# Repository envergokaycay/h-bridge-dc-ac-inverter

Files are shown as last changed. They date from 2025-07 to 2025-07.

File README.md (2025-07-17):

# Wireless Power Transfer System for Electric Vehicles

> 👇 Below you can see the inverter board and a real-time working demo:

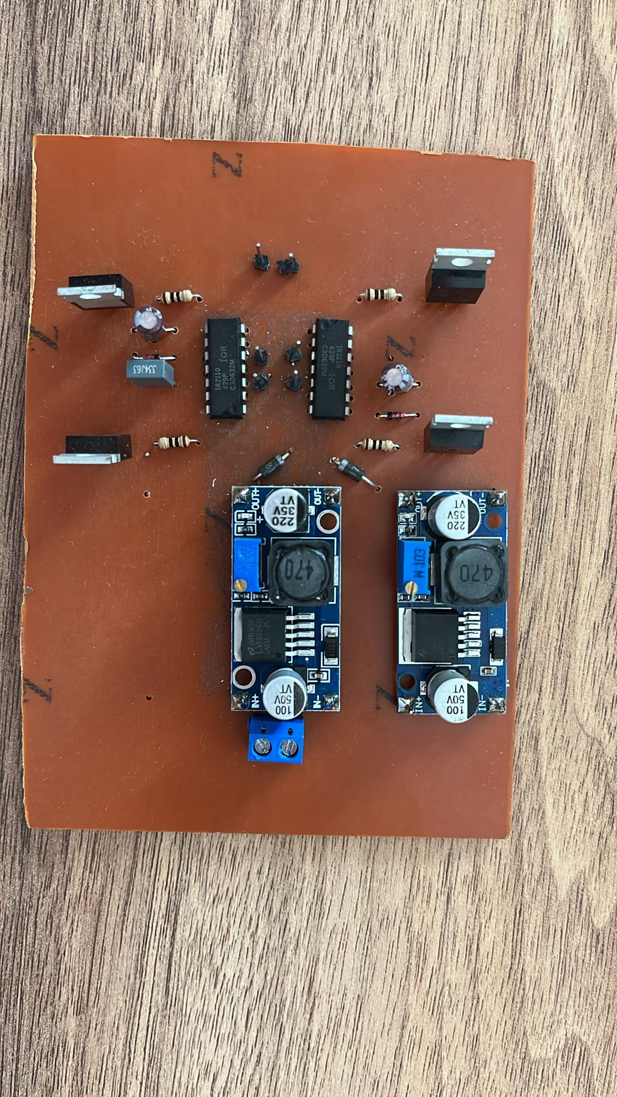
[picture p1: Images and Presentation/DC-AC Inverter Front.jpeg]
Inverter Front View


Operating Demo

## 📌 Project Summary
This project presents a **wireless power transfer (WPT)** system prototype aimed at demonstrating the basic principles of resonant inductive coupling for electric vehicle (EV) charging applications. The prototype is based on an **Arduino-controlled** system that generates a high-frequency AC output using a **H-bridge inverter**, optimized for energy transfer over short distances via an air-core coil pair.

This project was developed as a senior design (bitirme) project in the Electrical and Electronics Engineering Department.

---

## ⚙️ Technical Features

- **Input Voltage:** 24V DC
- **Output Voltage:** ~18V AC (square wave, measured ≈3V AC RMS on multimeter) 
- **Control:** Arduino Uno R3-based PWM generation
- **Topology:** H-Bridge Inverter using IRFZ44N MOSFETs and IR2110 Gate Drivers
- **Regulation:** LM2596 Buck Converter for voltage stepping
- **Rectification:** Fast recovery Schottky diodes at receiver side
- **PCB Design Software:** KiCad 9.0

---

## 🔧 Hardware and Software Used

- **Microcontroller:** Arduino Uno R3  
- **H-Bridge Topology:** Implemented using IRFZ44N MOSFETs  
- **Gate Driver:** IR2110  
- **DC-DC Regulator:** LM2596 (Used to step down the 24V input to 12V to power the IR2110 gate driver ICs. Additionally, another LM2596 module was configured to provide a 5V regulated output to safely interface the Arduino Uno R3’s PWM control signals with the IR2110 inputs.)  
- **Protection Diodes:** 1N5817 Schottky Diodes  
- **PCB Design:** KiCad 9.0 (schematic and PCB design)

---

## ⚙️ PCB Production

The PCB for the inverter stage was fully fabricated by hand, using personal resources and without relying on any professional PCB manufacturing service. The entire process — including etching, manual drilling, and component soldering — was carried out with basic tools, showcasing a hands-on, resourceful approach to hardware prototyping under limited conditions.

---

## 🧪 Testing and Results

- Square wave signal confirmed on the output using an oscilloscope  
- Successful power transfer to receiver coil  
- 3D visualization used for mechanical validation

---

## 📂 Suggested Folder Structure

- `DC-AC Inverter with H-Bridge/`  
  ├── `Code/`  
  ├── `Images and Presentation/`  
    ├── [Operating.mp4](https://www.youtube.com/shorts/zgLSwQ5zg5Q)  
    └── [Wireless Electric Vehicle Charging System KTU EEE.mp4](https://www.youtube.com/shorts/1_IPSUS-X5c)  
  ├── `PCB/`  
    ├── `3D/`  
    ├── `BOM/`  
    ├── `Drill/`  
    └── `Gerber/`  
  ├── `Schematics/`  
  ├── `Simulation Graphs/`  
  └── `README.md`

---

## 📝 Notes

- This circuit is part of a larger system intended to provide an efficient power transfer layer for wireless charging of electric vehicles.  
- All components were selected based on reliable datasheet references and added to KiCad libraries accordingly.

---

## 📚 Future Improvements

- Implement closed-loop current control via feedback
- Design custom receiver coil enclosure
- Replace Arduino with STM32 for better signal precision
- Improve EMI shielding and cooling

---

## 📬 Contact

If you have any questions or want to collaborate, feel free to reach out via GitHub or [LinkedIn](https://www.linkedin.com/in/envergokaycay/).

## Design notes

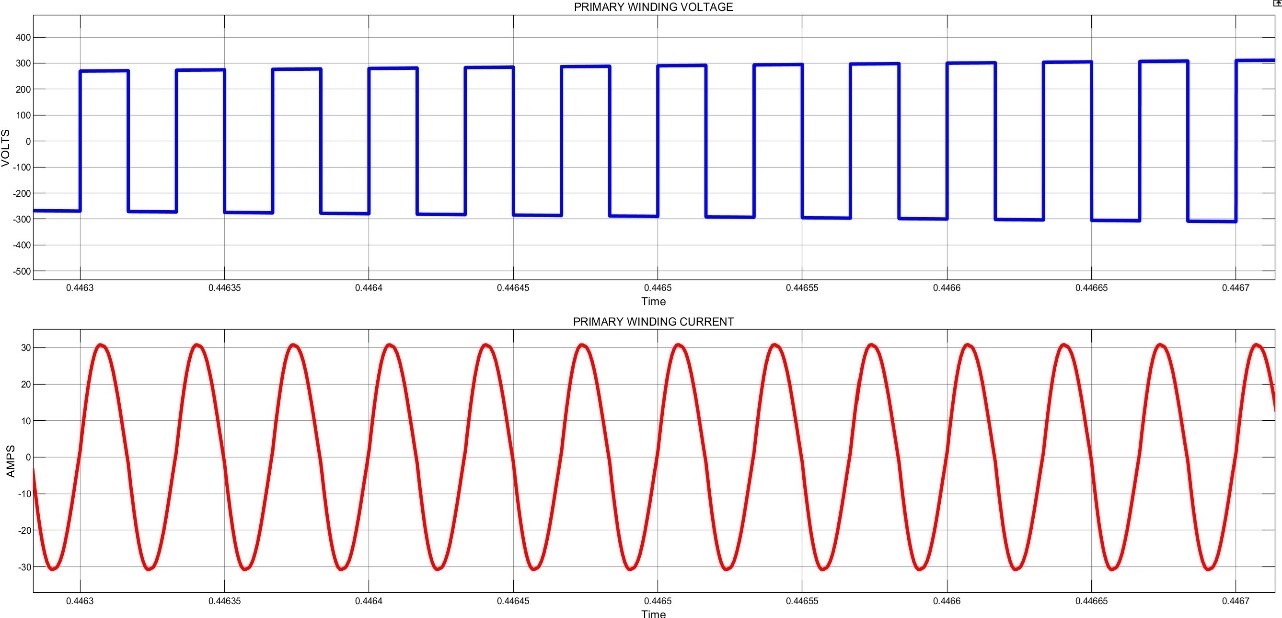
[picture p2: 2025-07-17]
Simulation Graphs/Primary Winding Graphs.jpg

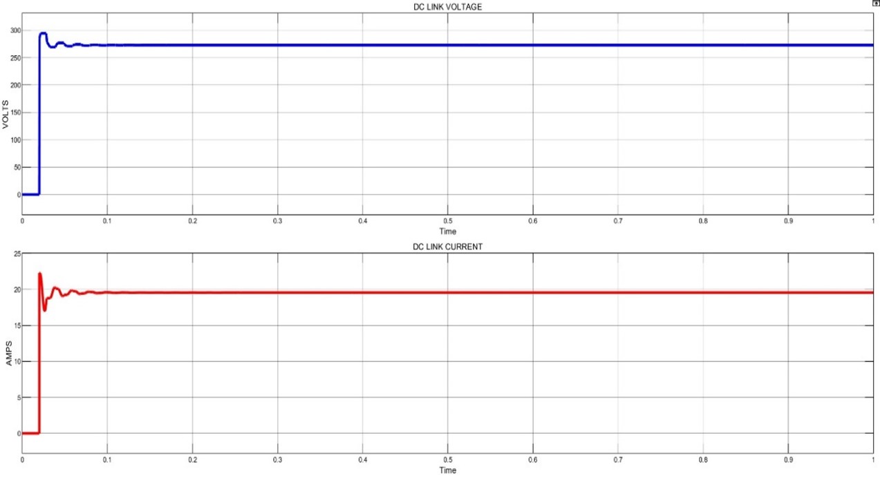
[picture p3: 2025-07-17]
Simulation Graphs/DC-Link Graphs.jpg

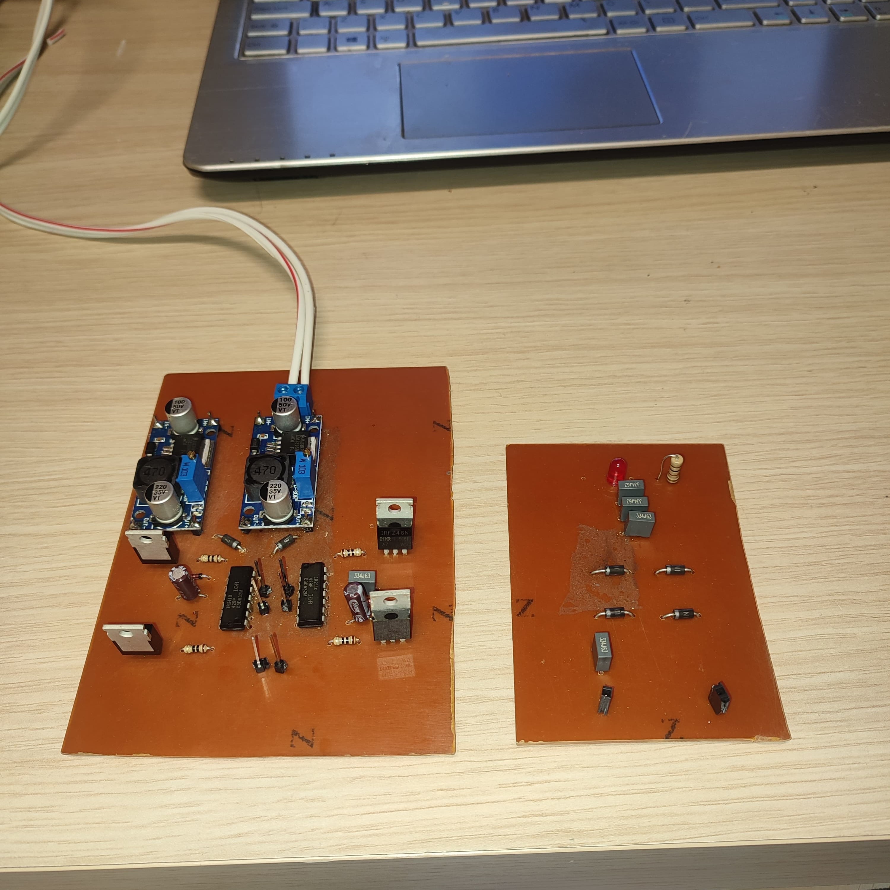
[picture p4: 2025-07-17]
Images and Presentation/Transmitter and Receiver.jpeg

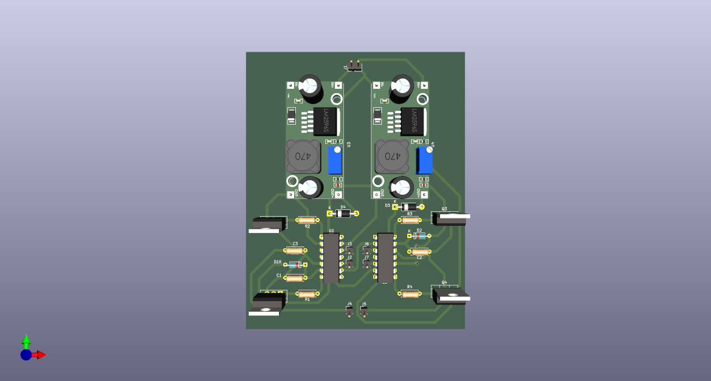
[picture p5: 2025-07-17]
PCB/3D/DC-AC Inverter.png

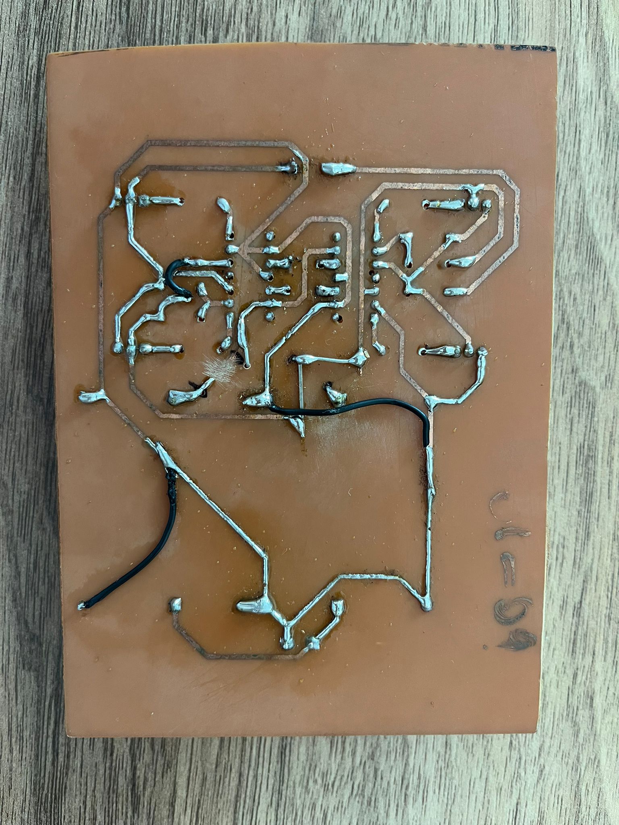
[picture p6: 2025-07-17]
Images and Presentation/DC-AC Inverter Back.jpeg

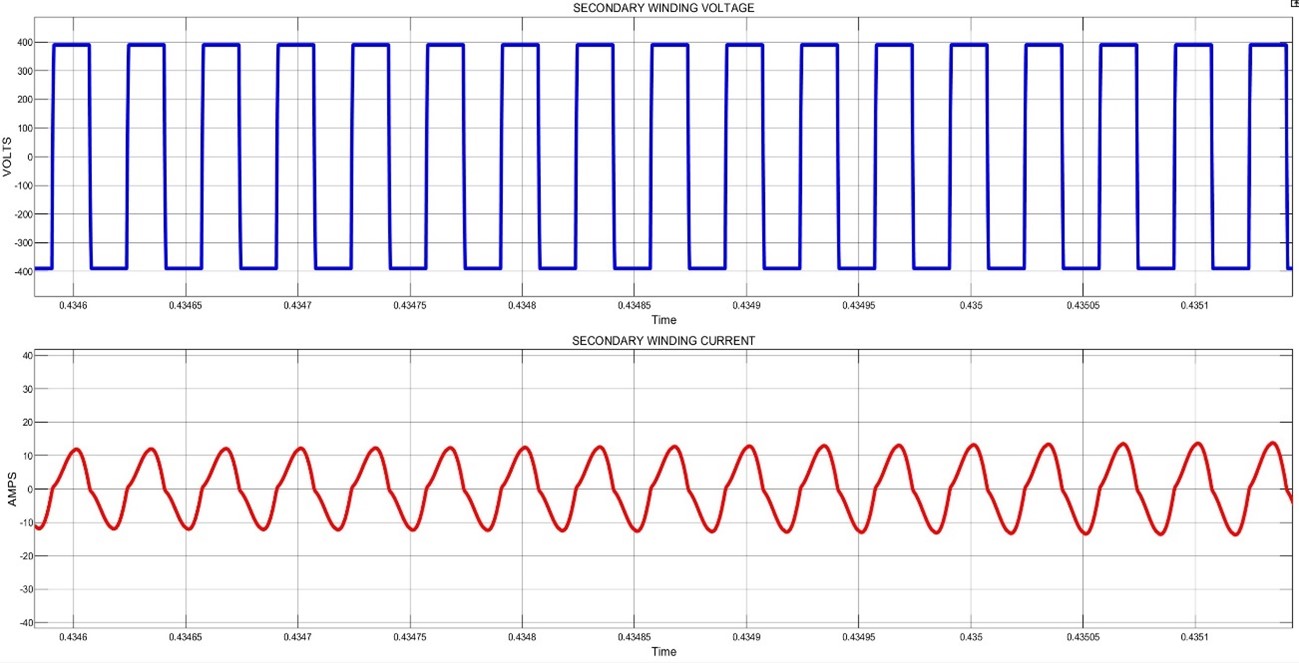
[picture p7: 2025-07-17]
Simulation Graphs/Secondary Winding Graphs.jpg

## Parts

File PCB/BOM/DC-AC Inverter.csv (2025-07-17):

Id | Designator | Footprint | Quantity | Designation | Supplier and ref
1 | D2,D1 | D_DO-35_SOD27_P7.62mm_Horizontal | 2 | 1N4148
2 | D4,D3 | D_DO-41_SOD81_P10.16mm_Horizontal | 2 | 1N5817
3 | Q3,Q4,Q2,Q1 | TO-220-3_Vertical | 4 | IRFZ46NPBF
4 | J7,J3,J2,J6 | PinHeader_1x01_P2.54mm_Vertical | 4 | Conn_01x01_Pin
5 | J5,J4 | PinHeader_1x01_P2.54mm_Vertical | 2 | Conn_01x01_Socket
6 | R1,R4,R2,R3 | R_Axial_DIN0207_L6.3mm_D2.5mm_P7.62mm_Horizontal | 4 | 10Ω
7 | C3 | R_Axial_DIN0207_L6.3mm_D2.5mm_P7.62mm_Horizontal | 1 | 330nF
8 | U3,U4 | YAAJ_DCDC_StepDown_LM2596 | 2 | YAAJ_DCDC_StepDown_LM2596
9 | U1,U2 | DIP-14_W7.62mm | 2 | IR2110
10 | J1 | PinHeader_1x02_P2.54mm_Vertical | 1 | Conn_01x02_Socket
11 | C1,C2 | R_Axial_DIN0207_L6.3mm_D2.5mm_P7.62mm_Horizontal | 2 | 0.1µF

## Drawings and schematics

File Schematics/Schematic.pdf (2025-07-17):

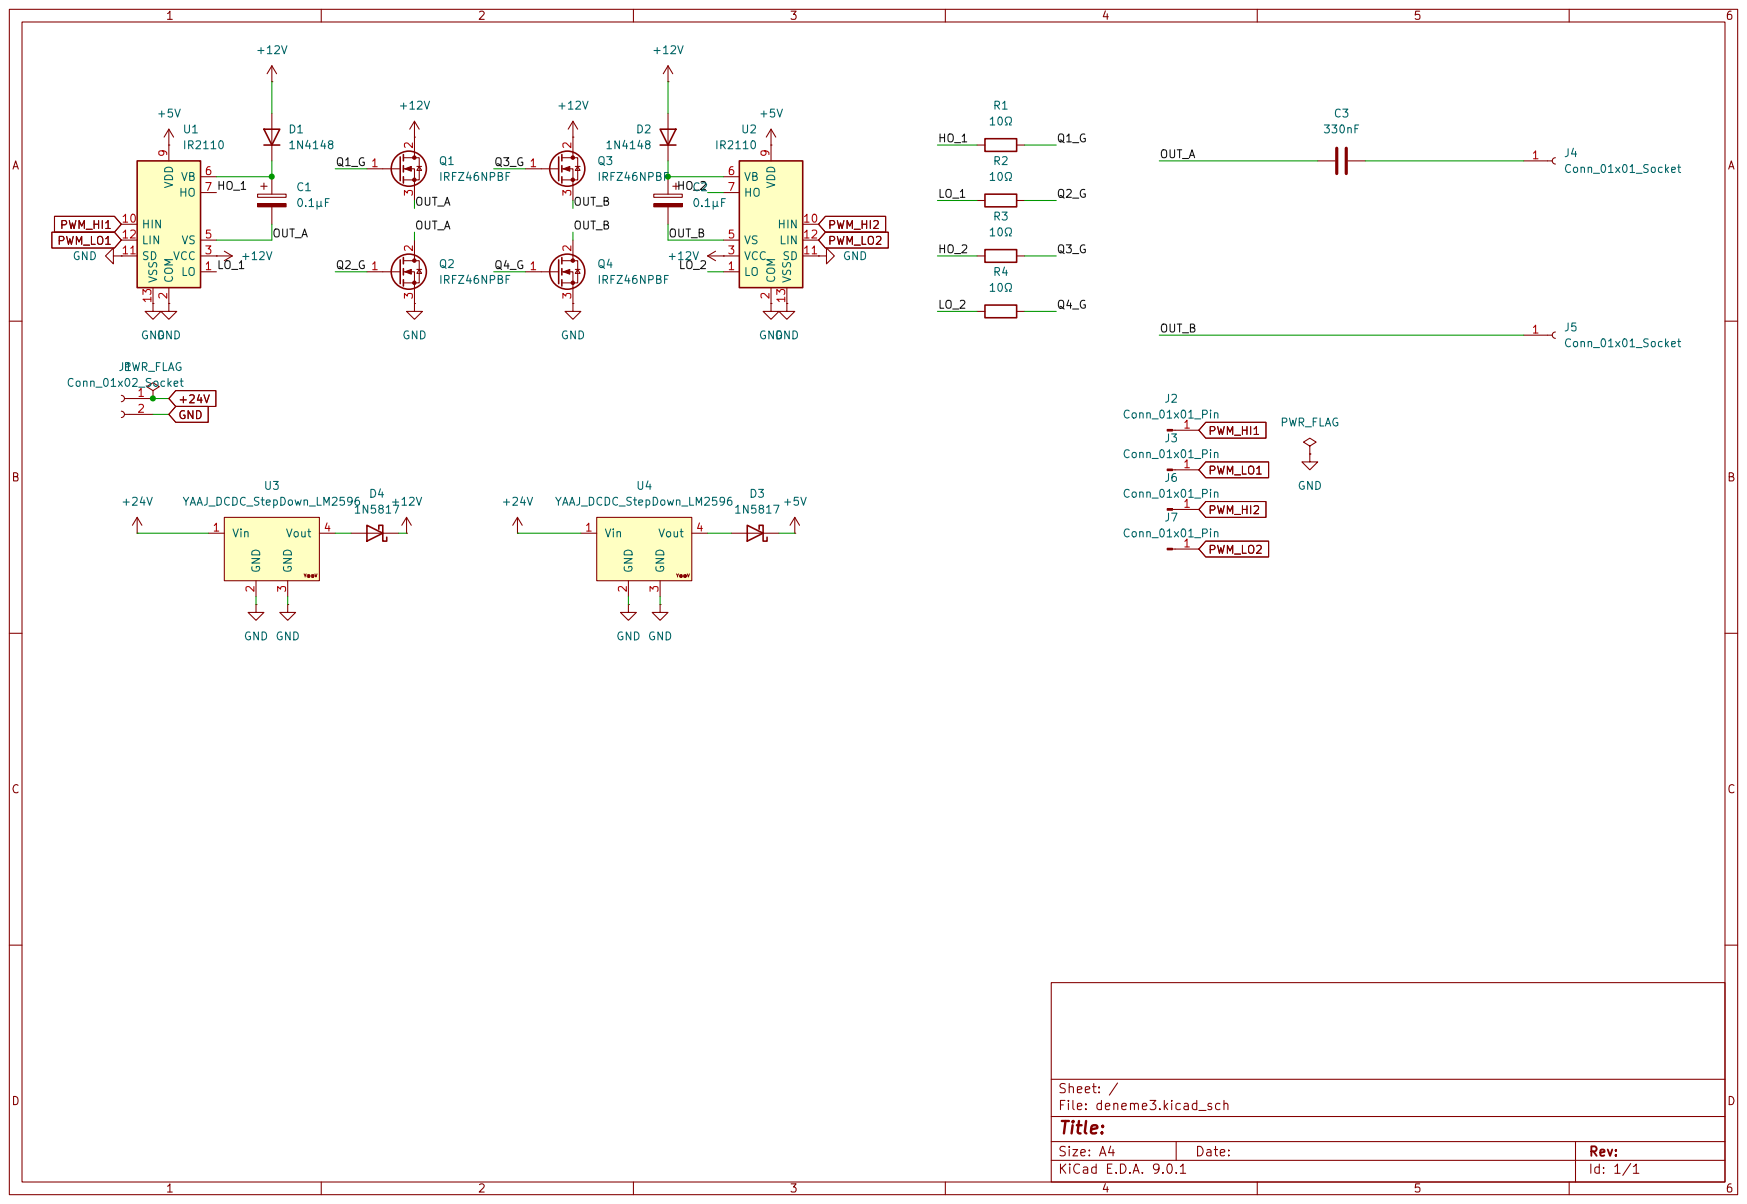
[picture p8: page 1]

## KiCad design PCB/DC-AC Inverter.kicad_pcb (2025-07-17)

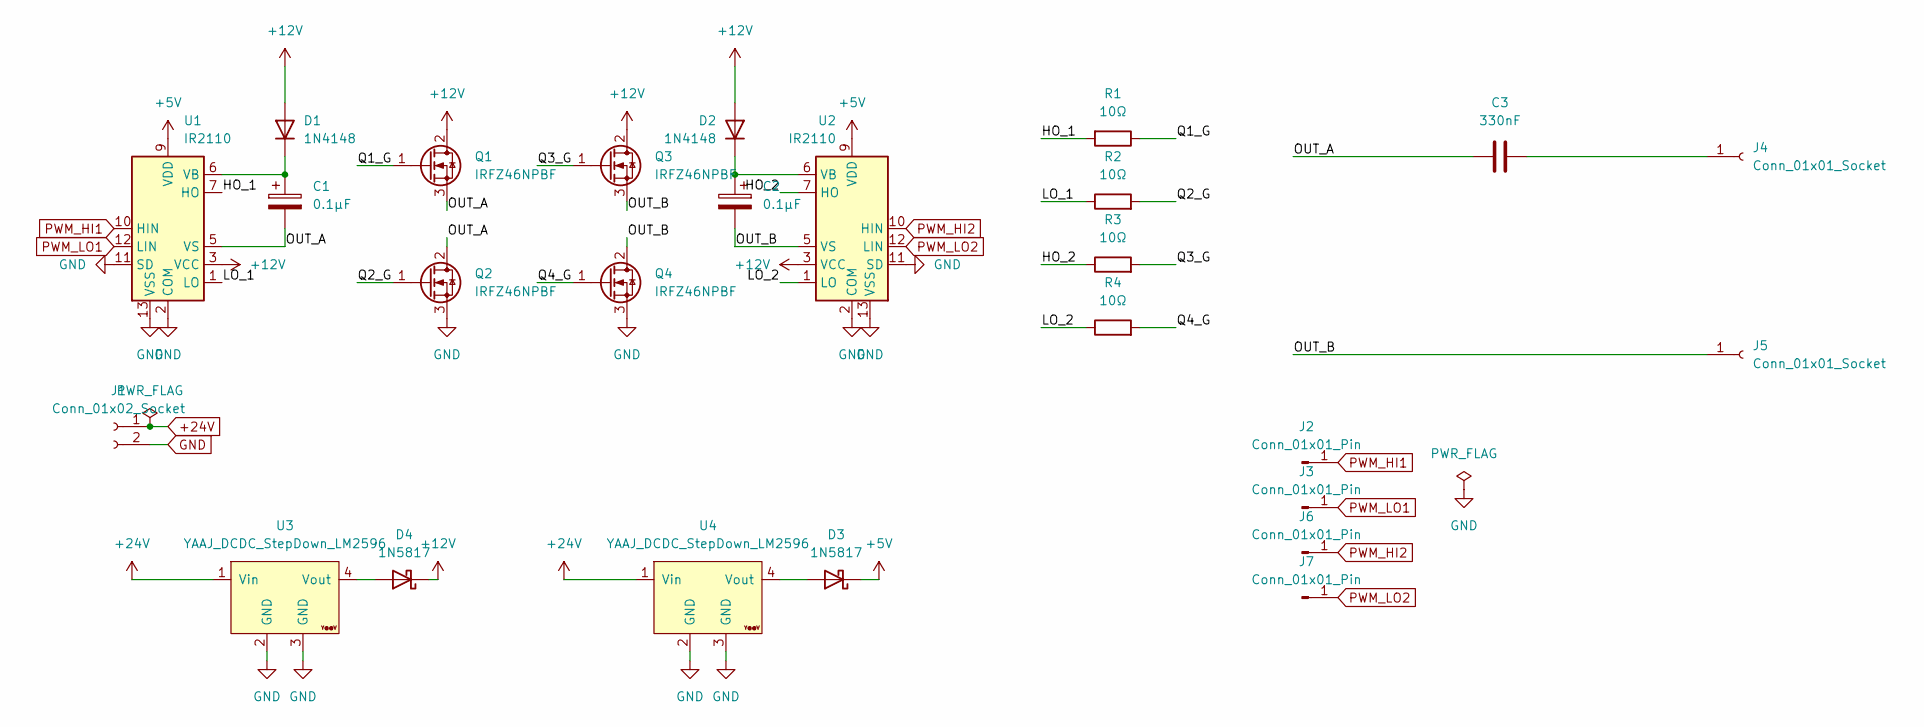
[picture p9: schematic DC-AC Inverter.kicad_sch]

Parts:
C1, C2: 0.1µF; R_Axial_DIN0207_L6.3mm_D2.5mm_P7.62mm_Horizontal
C3: 330nF; R_Axial_DIN0207_L6.3mm_D2.5mm_P7.62mm_Horizontal
D1, D2: 1N4148; D_DO-35_SOD27_P7.62mm_Horizontal
D3, D4: 1N5817; D_DO-41_SOD81_P10.16mm_Horizontal
J1: Conn_01x02_Socket; PinHeader_1x02_P2.54mm_Vertical
J2, J3, J6, J7: Conn_01x01_Pin; PinHeader_1x01_P2.54mm_Vertical
J4, J5: Conn_01x01_Socket; PinHeader_1x01_P2.54mm_Vertical
Q1, Q2, Q3, Q4: IRFZ46NPBF; TO-220-3_Vertical
R1, R2, R3, R4: 10Ω; R_Axial_DIN0207_L6.3mm_D2.5mm_P7.62mm_Horizontal
U1, U2: IR2110; DIP-14_W7.62mm
U3, U4: YAAJ_DCDC_StepDown_LM2596

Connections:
+5V: D3.1 (K), U1.9 (VDD), U2.9 (VDD)
+12V: D1.2 (A), D2.2 (A), D4.1 (K), Q1.2 (D), Q3.2 (D), U1.3 (VCC), U2.3 (VCC)
+24V: J1.1, U3.1 (Vin), U4.1 (Vin)
/HO_1: R1.2, U1.7 (HO)
/HO_2: R3.1, U2.7 (HO)
/LO_1: R2.1, U1.1 (LO)
/LO_2: R4.1, U2.1 (LO)
/OUT_A: C1.2, C3.1, Q1.3 (S), Q2.2 (D), U1.5 (VS)
/OUT_B: C2.2, J5.1, Q3.3 (S), Q4.2 (D), U2.5 (VS)
/Q1_G: Q1.1 (G), R1.1
/Q2_G: Q2.1 (G), R2.2
/Q3_G: Q3.1 (G), R3.2
/Q4_G: Q4.1 (G), R4.2
GND: J1.2, Q2.3 (S), Q4.3 (S), U1.2 (COM), U1.11 (SD), U1.13 (VSS), U2.2 (COM), U2.11 (SD), U2.13 (VSS), U3.2 (GND), U3.3 (GND), U4.2 (GND), U4.3 (GND)
unnamed: C1.1, D1.1 (K), U1.6 (VB)
unnamed: C2.1, D2.1 (K), U2.6 (VB)
unnamed: D3.2 (A), U4.4 (Vout)
unnamed: D4.2 (A), U3.4 (Vout)
unnamed: C3.2, J4.1
PWM_HI1: J2.1, U1.10 (HIN)
PWM_HI2: J6.1, U2.10 (HIN)
PWM_LO1: J3.1, U1.12 (LIN)
PWM_LO2: J7.1, U2.12 (LIN)

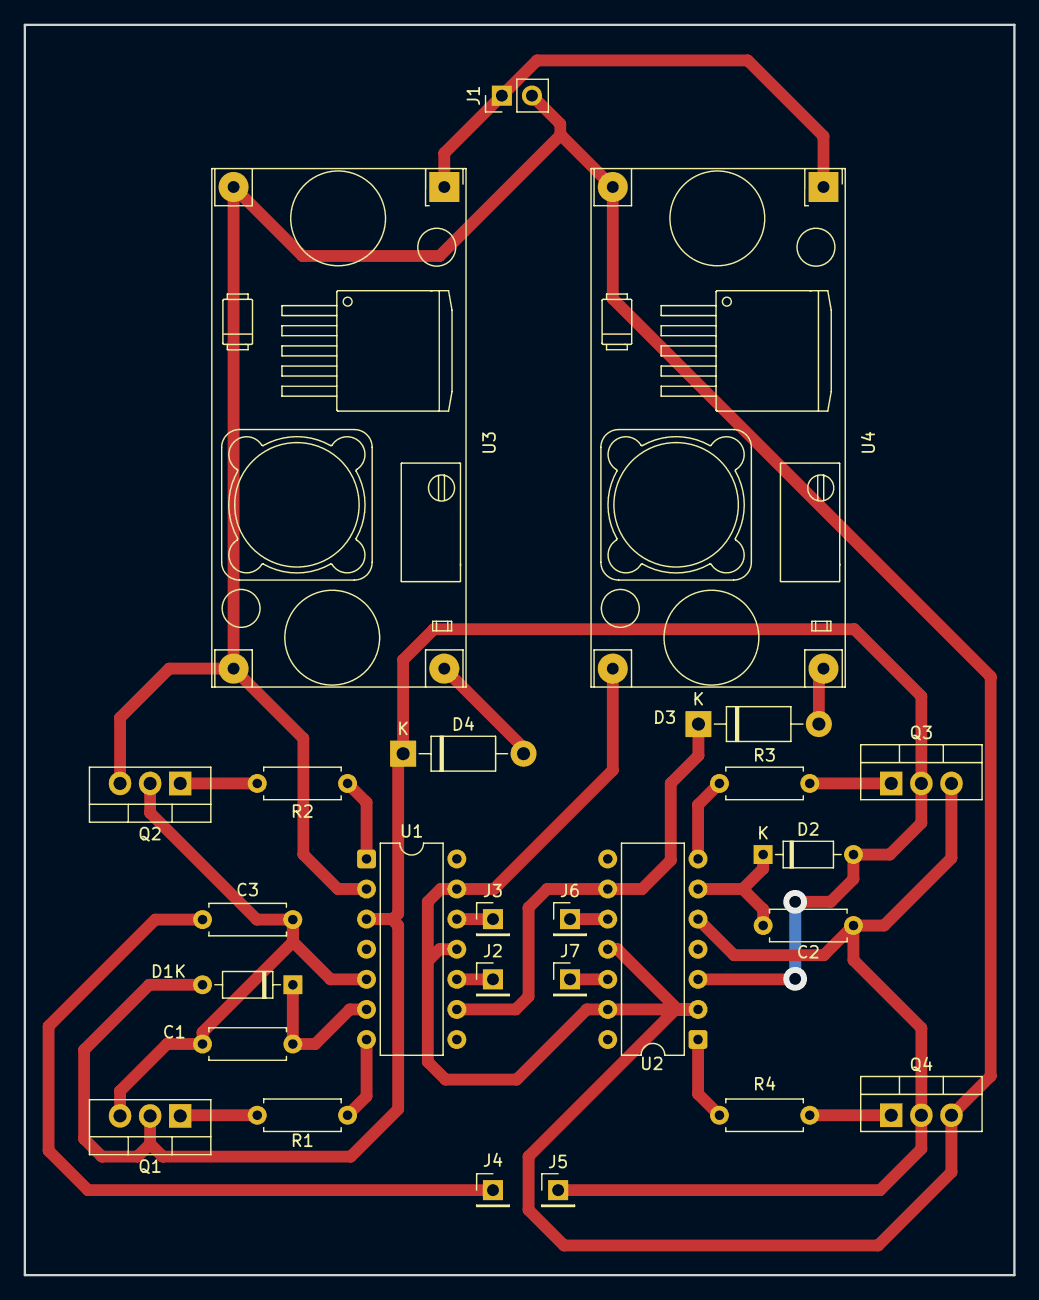
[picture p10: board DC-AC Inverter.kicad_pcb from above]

Board: 2 copper layers, 83.5 x 105.5 mm, 26 parts (0 on the bottom side), 23 nets.

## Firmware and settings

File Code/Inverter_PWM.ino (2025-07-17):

// === Pin Tanımları ===
const int HIN1 = 9;    // OC1A - Timer1
const int LIN1 = 10;   // OC1B - Timer1
const int HIN2 = 3;    // Software PWM
const int LIN2 = 11;   // Software PWM

// === Zamanlama Ayarları ===
const int deadTimeMicros = 5;     // 5 µs dead time
const int onTimeMicros = 20;      // 20 µs aktif süre (%50 duty @ 20kHz)

void setup() {
  // Pin modları
  pinMode(HIN1, OUTPUT);
  pinMode(LIN1, OUTPUT);
  pinMode(HIN2, OUTPUT);
  pinMode(LIN2, OUTPUT);

  // === Timer1 Ayarı (Donanımsal PWM için) ===
  TCCR1A = 0;
  TCCR1B = 0;

  // Fast PWM, Mode 14: ICR1 top
  TCCR1A |= (1 << COM1A1) | (1 << COM1B1); // OC1A & OC1B non-inverting
  TCCR1A |= (1 << WGM11);
  TCCR1B |= (1 << WGM12) | (1 << WGM13);
  TCCR1B |= (1 << CS10); // No prescaler

  ICR1 = 800;     // 16 MHz / 800 = 20kHz
  OCR1A = 0;      // Başta OFF
  OCR1B = 0;      // Başta OFF
}

void loop() {
  // === Timer1: HIN1 ve LIN1 kontrolü (donanımsal) ===

  // Üst MOSFET ON (HIN1), Alt OFF (LIN1)
  OCR1A = 400;  // %50 duty
  OCR1B = 0;
  delayMicroseconds(onTimeMicros);

  // Her iki çıkışı kapat (dead time)
  OCR1A = 0;
  delayMicroseconds(deadTimeMicros);

  // Alt MOSFET ON (LIN1), Üst OFF (HIN1)
  OCR1B = 400;
  OCR1A = 0;
  delayMicroseconds(onTimeMicros);

  // Her iki çıkışı kapat (dead time)
  OCR1B = 0;
  delayMicroseconds(deadTimeMicros);

  // === Yazılımsal PWM: HIN2 ve LIN2 ===

  // Üst MOSFET ON (HIN2), Alt OFF (LIN2)
  digitalWrite(HIN2, HIGH);
  digitalWrite(LIN2, LOW);
  delayMicroseconds(onTimeMicros);
  digitalWrite(HIN2, LOW);
  delayMicroseconds(deadTimeMicros);

  // Alt MOSFET ON (LIN2), Üst OFF (HIN2)
  digitalWrite(LIN2, HIGH);
  digitalWrite(HIN2, LOW);
  delayMicroseconds(onTimeMicros);
  digitalWrite(LIN2, LOW);
  delayMicroseconds(deadTimeMicros);
}
